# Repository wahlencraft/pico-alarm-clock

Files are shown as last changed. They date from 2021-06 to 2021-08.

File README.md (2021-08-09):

# Pico Alarm Clock

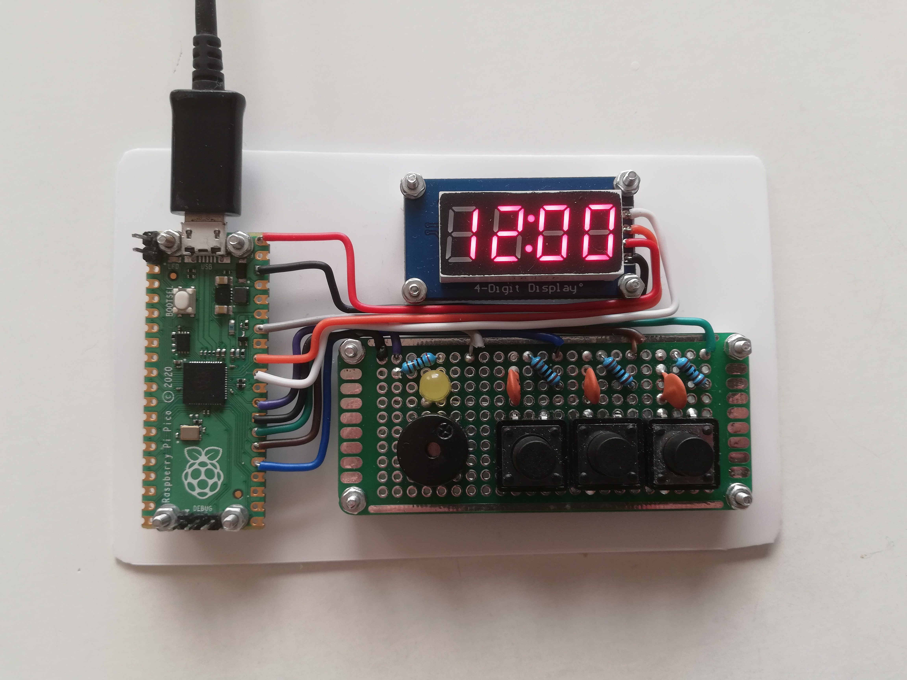
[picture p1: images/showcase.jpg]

## Introduction
This is an alarm clock that is running on Raspberry Pi Pico and is displaying
on a TM1637 7-segment display. In this project I try to stay close to the
hardware and implement what I can from scratch. For example, I wrote my own
library for the display and I use real hardware interrupts for button clicks and
time based events.

I made a short [YouTube video](https://youtu.be/I4LGKX7zu-I) showing some of the 
functionallity of the clock.

## Dependencies
* [Raspberry Pi Pico SDK](https://github.com/raspberrypi/pico-sdk): The
  standard library for working with Pico.
* [Pico Extras](https://github.com/raspberrypi/pico-extras): Some additional
  libraries. I needed this for putting the Pico in sleep mode.
* [TM1637-pico](https://github.com/wahlencraft/TM1637-pico): My own library for
  writing to the 7-segment display.

## Setup
### Hardware

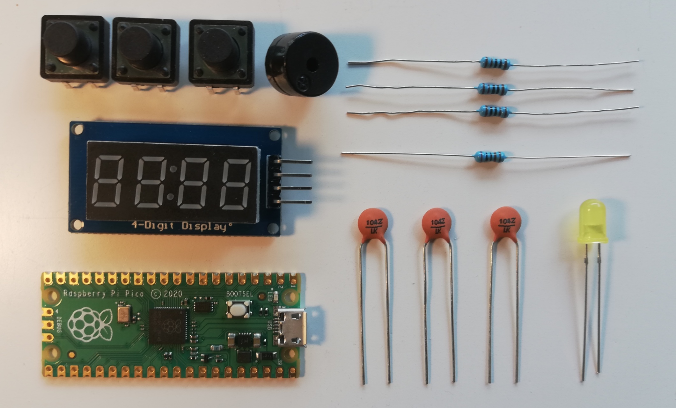
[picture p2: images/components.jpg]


* Raspberry Pi Pico
* TM1637 7-segment display
* Passive buzzer
* 3 Buttons
* Led (I used a yellow one)
* 4 Resistors: 3 for button debouncing (1k) and 1 for the LED (2k). Exact
  sizes are not important and might vary depending on the buttons and LED.
* 3 Ceramic capacitors (100 nF) for button debouncing.
* A micro USB power cable and 5V power supply.

### Circuit
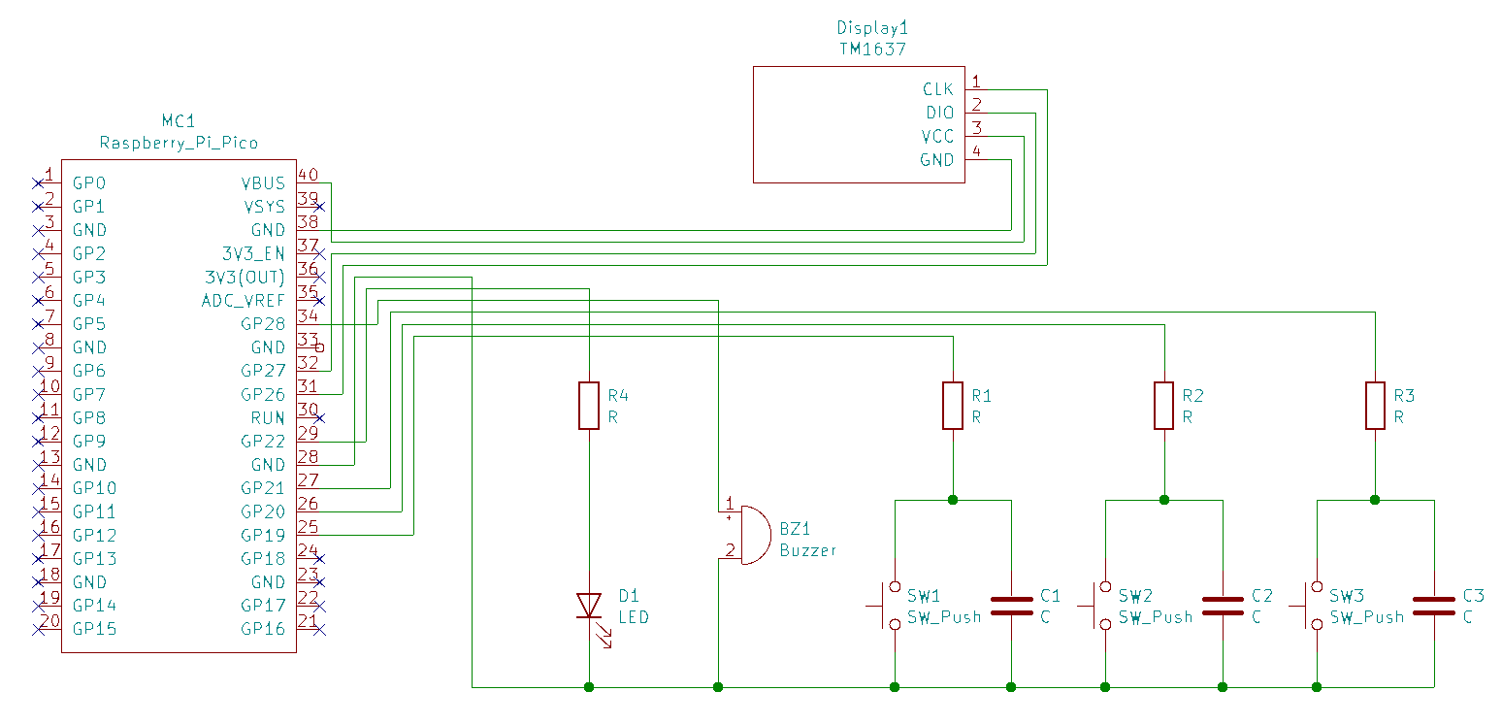
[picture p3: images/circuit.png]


### Load Code
A .elf and .uf2 binary can be downloaded for 1.0 or later. You can also clone the repository and build from source. Then the files will apear in the `build/src` directory.

#### UF2
Hold down the bootsel button and plug Rasperry Pi Pico into a USB port on your computer (Windows or Linux). The Pico will mount as a USB Mass Storage
Device. Drag and droop the .uf2 file on the Pico.

#### ELF
The .elf file can be loaded to the pico over UART. This is most easily done from a Rasperry Pi (computer), but can also be done with another Pico using Picoprobe. See [Getting started with Raspberry Pi Pico: Appendix A](https://datasheets.raspberrypi.org/pico/getting-started-with-pico.pdf)

If loading code over UART (from for example a Raspberry Pi) some unexpected
behavior arises.

The openocd reset command does not work with this code. I don't know why but a
workaround is to remove that from the command. Load code with:
`openocd -f interface/raspberrypi-swd.cfg -f target/rp2040.cfg -c "program src/alarm-clock.elf verify exit"`
Then restart the Pico manually by using a reset switch or un- and re-plugging the
power.

## Usage
Under normal circumstances will the display show current time and wait for
alarms to fire. When the clock is turned on the time will be `Monday 00:00:00`
and there is no set alarms. To change the time or add an alarm, open the menu.
### The Settings Menu
If any button is pressed the menu will open. In the menu you can change the
display brightness, set clock time and set alarms. See the flowchart below for
a quick overview or read the following sections for an in-depth description.
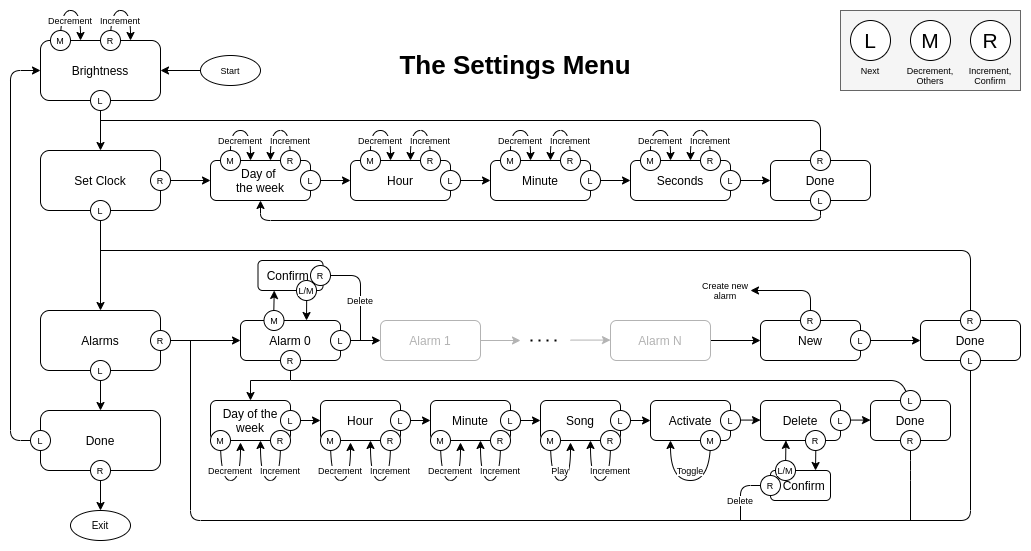
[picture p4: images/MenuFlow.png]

#### Brightness
In the brightness state the display will show `br: x`, where `x` will change with
the brightness level. In- or decrease the brightness with the M and R buttons.
The brightness has 8 levels, ranging from 0 to 7. Although there seems to be
a very little change in brightness in the higher levels.
#### Set Clock
To enter Set Clock press the R button when the display shows `SEt`. Here you
can change the running clock.
- **Day of the week** (`da:xx`): In or decrease with the M and R buttons.
  A list of the days and their two letters:
  - Monday: `mo`
  - Tuesday: `tU`
  - Wednesday: `wE`
  - Thursday: `tH`
  - Friday: `Fr`
  - Saturday: `SA`
  - Sunday: `SU`
- **Hour** (`Hr:xx`): In- or decrease with the M and R buttons.
- **Minute** (`mi:xx`): In- or decrease with the M and R buttons.
- **Seconds** (`SE:xx`): Zero the counter with the M or R button. Please note
  that this only sets the current second to 0, it doesn't restart the RTC. This
  makes it impossible to set exactly when a second starts.
- **Done** (`done`): Go back to the main menu.
#### Alarms
To enter Alarms press the R button when the display shows `ALAr`. Then you will
be navigated to the first alarm, called `AL: 0`. Given that this alarm exists.
Otherwise you will see `nEw` on the display.

To create a new alarm, navigate to `nEw` and press R. That will open the edit
state for a new alarm.

To edit an existing alarm, navigate to `AL: x` and press R.

Editing an alarm works a lot like setting the clock. With some differences:
- You can not specify seconds
- Song (`So`). This is what sound the alarm will make. Use the
  R button to increment song and M button to listen to it.
- Activate (`Act`): Toggle active status of this alarm. The LED will be on if
  the alarm is on and off if the alarm is off. When creating a new alarm is it
  by default on.
- Delete (`dEL`): Exit and delete the current alarm. Confirm deletion with R,
  abort with L or M.
- Done (`done`): Will fail if there already is an alarm with the same time.

Note that when exiting from `done`, you will always get to the first alarm
`AL: 0`. This is because the list of alarms will always be in chronological
order, and might need rearrangement after an edit.

To delete an alarm, navigate to it and press M. Then press R. To abort press
any other button.
### The Alarms
You can have an unlimited numbers of alarms. Every alarm has a time (specified
by day of the week, hour and minute), a song (what tones will play when it
fires) and an active status. To change these see [this section](#alarms).

When an alarm fires it will play it's song and blink the LED. It will continue
until any button is pressed to stop it or the max duration has passed (default
5 minutes).

## Making modifications
If you want to make some modifications to the program i would recommend
starting with these files.

* [pins.h](src/pins.h): Here you can change what physical pin will have what
  function. So if your prototype does not have the same connections as mine you
  need to make changes here.
* [timout_timer.h](src/timeout_timer.h): Here you will find `ALARM_TIMEOUT`
  which determines for how long an alarm should fire before turning off
  automatically.
* [song_def.c](src/song_def.c): Here the songs (alarm sounds) are
  defined. You can edit, add and remove songs. Please note that what tones that
  resonates best depends on your buzzer, so this might be necessary if you have
  a very different one from mine.

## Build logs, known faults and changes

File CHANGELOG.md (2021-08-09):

# Changelog

## [1.0.0] - 2021-08-09
### Added
- You can now delete an alarm directly from the alarm edit menu.
- You can now listen to a song directly from the alarm edit menu.
- New songs.
### Changed
- There is now a max duration for alarms (5 minutes).
- If attempting to add an alarm which collides with an already existing alarm,
  it will fail, and the display will blink.

## [0.3.0] - 2021-07-10
### Added
- Enable/Disable alarms
- LED support.
  - LED blinks along with the sound when an alarm is firing.
  - In alarm settings, LED indicate if alarm is disabled or enabled.

## [0.2.0] - 2021-06-24
### Added
- Create, edit and remove alarms
### Changed
- The brightness setting can now be increased and decreased, just like the other
  settings.

## [0.1.0] - 2021-06-15
### Added
- Show time in 24h format.
- A menu oriented with 3 buttons. Ability to change display brightness and
  clock time.
- Some work in progress for alarms:
  - Ability to play sounds (code only).
  - Ability to store alarms (code only).

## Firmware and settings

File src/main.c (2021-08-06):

/**
 * main.c
 *
 * Some important functions and the upper level state-machine.
 **/

/*******************************************************************************
 *  Includes
 ******************************************************************************/
#include <stdlib.h>
#include <stdio.h>
#include <stdbool.h>

#include <pico/stdlib.h>
#include <pico/sleep.h>
#include <hardware/rtc.h>
#include <pico/util/datetime.h>
#include <PicoTM1637.h>
#include <hardware/sync.h>

#include <pins.h>
#include <helpers.h>
#include <settings.h>
#include <node.h>
#include <alarm.h>
#include <timeout_timer.h>

/*******************************************************************************
 * Globals
 ******************************************************************************/

volatile struct GlobBinder *state;  // Binder for all states in the global state machine

/*******************************************************************************
 * Functions
 ******************************************************************************/

static void fire_alarm(void) {
  printf("START NEW ALARM\n");
  uint32_t hz = clock_get_hz(clk_sys);
  printf("  Running at %f MHz\n", (float) hz/1000000);
  state->alarmMode = true;
  start_alarm_timer();
}

static void gpio_callback(uint gpio, uint32_t events) {
  DEBUG_PRINT(("Interrupted by GPIO %d\n", gpio));
  DEBUG_PRINT(("  alarmMode: %d, sleepMode: %d, buttonBuffer: %d\n",
      state->alarmMode, state->sleepMode, state->buttonBuffer));
  if (state->alarmMode) {
    DEBUG_PRINT(("    Turn of alarm!\n"));
    state->alarmMode = false;
  } else {
    state->sleepMode = false;
    state->buttonBuffer = gpio;
  }
  DEBUG_PRINT(("  alarmMode: %d, sleepMode: %d, buttonBuffer: %d\n",
      state->alarmMode, state->sleepMode, state->buttonBuffer));
}

static int64_t alarm_callback(alarm_id_t id, void *user_data) {
  DEBUG_PRINT(("alarm_callback: Timer %d fired! ", (int) id));
  display_h_min();
  int64_t nextCallback = update_running_song();
  DEBUG_PRINT(("Again in %lld ms\n", nextCallback));
  // Can return a value here in us to fire in the future
  return nextCallback*1000;
}

static void setup_button(int gpio) {
  gpio_pull_up(gpio);
  gpio_set_irq_enabled_with_callback(
      gpio,
      GPIO_IRQ_EDGE_RISE,
      true,
      &gpio_callback
      );
}

/* Put cpu to sleep until next minute. Then display time. */
static void sleep_to_next_min() {
  // Set next wakeup
  datetime_t time = {
    .year = -1,
    .month = -1,
    .day = -1,
    .dotw = -1,
    .hour = -1,
    .min = -1,
    .sec = 0
  };
  uart_default_tx_wait_blocking();
  TM1637_wait();
  sleep_goto_sleep_until(&time, &display_h_min);
}

/* Put cpu to sleep until next alarm. Then display time and start alarmMode. */
void sleep_to_next_alarm(node_t *alarm) { 
  // Copy time
  datetime_t time;
  time.year = -1;
  time.month = -1;
  time.day = -1;
  time.dotw = alarm->time->dotw;
  time.hour = alarm->time->hour;
  time.min = alarm->time->min;
  time.sec = alarm->time->sec;
  
  // Prepare for sleep mode
  uart_default_tx_wait_blocking();
  TM1637_wait();
  
  // Go to sleep
  sleep_goto_sleep_until(&time, &fire_alarm);
}

/*******************************************************************************
 *  Main program
 *  - Initiate
 *  - Start main loop (the state machine)
 ******************************************************************************/
int main() {

  struct GlobBinder globalStruct = {.sleepMode = true, .buttonBuffer = 0};
  state = &globalStruct;
  
  stdio_init_all();
  uart_default_tx_wait_blocking();

  // Initiate
  TM1637_init(CLK_PIN, DIO_PIN);
  setup_button(LEFT_BUTTON);
  setup_button(MIDDLE_BUTTON);
  setup_button(RIGHT_BUTTON);
  DEBUG_WAIT((100));
  init_alarms();

  TM1637_clear();
  // Start the RTC
  rtc_init();
  datetime_t t = {
    .year = 1970,
    .month = 1,
    .day = 1,
    .dotw = 1, // 0 is Sunday
    .hour = 0,
    .min = 0,
    .sec = 0
  };

  // Switch to XOSC
  uart_default_tx_wait_blocking();
  sleep_run_from_xosc();
  TM1637_refresh_frequency();

  rtc_set_datetime(&t);

  // Setting cases
  #define SETT_NONE 0
  #define SETT_BRIGHT 1
  #define SETT_CLOCK 2
  #define SETT_ALARM 3
  #define SETT_DONE 4

  display_h_min();
  state->sleepMode = true;
  state->alarmMode = false;
  state->buttonBuffer = 0;

  node_t *runningAlarm = malloc(sizeof(runningAlarm));
  runningAlarm->time = malloc(sizeof(datetime_t));

  DEBUG_PRINT(("\nSTART MAIN LOOP\n"));
  // Main loop
  //
  // if alarmMode:
  //    play song (stay here until interupt)
  // else if sleepMode:
  //    if "alarm in 1 min" -> sleep_to_next_alarm
  //    else -> sleep_to_next_min
  // else: (button interupt)
  //    open settings menu
  while (true) {
    DEBUG_PRINT(("\n"));
    print_current_time();
    print_all_alarms();
    if (state->alarmMode) {
      rtc_disable_alarm();
      start_song(runningAlarm->song);
      alarm_id_t almID = add_alarm_in_us(0, alarm_callback, NULL, true);
      DEBUG_PRINT(("Alarm %d started\n", almID));
      while (state->alarmMode) {
        if (alarm_timeout()) {
          state->alarmMode = false;
          DEBUG_PRINT(("Alarm fired for too long. Turning off.\n"));
          break;
        }
      }
      cancel_alarm(almID);
      stop_song();
    } else if (state->sleepMode) {
      if (is_alarm_in_1_min(runningAlarm)) {
        DEBUG_PRINT(("Found Alarm! Fire at "));
        print_time(runningAlarm->time, 0);
        sleep_to_next_alarm(runningAlarm);
      } else {
        sleep_to_next_min();
      }
    } else {
      // Interrupted from by button. Open settings menu.
      rtc_disable_alarm();
      DEBUG_PRINT(("Woke up by interupt!\n"));
      int button;
      int setting = 1;
      state->buttonBuffer = 0;
      while (setting != 0) {
        DEBUG_PRINT(("Outer setting loop. Case is %d\n", setting));
        switch (setting) {

          case SETT_BRIGHT:
            DEBUG_PRINT((" Enter SETT_BRIGHT\n"));
            setting = brightness_setting(SETT_BRIGHT);
            break;

          case SETT_CLOCK:
            DEBUG_PRINT((" Enter SETT_CLOCK\n"));
            setting = set_clock_setting(SETT_CLOCK);
            break;

          case SETT_ALARM:
            DEBUG_PRINT((" Enter SETT_ALARM\n"));
            setting = set_alarm_setting(SETT_ALARM);
            break;

          case SETT_DONE:
            DEBUG_PRINT((" Enter SETT_DONE\n"));
            setting = done_setting(SETT_DONE);
            break;

          default:
            // Should not happen
            DEBUG_PRINT(("Runntime Error, buttonBuffer = %d\n",
                  state->buttonBuffer));
            return 1;
        }
      }
      // Exit settings menu.
      display_h_min();
      state->sleepMode = true;
    }
  }
}

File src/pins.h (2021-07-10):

#ifndef PINS_H_H
#define PINS_H_H

/**
 * pins.h
 *
 * Define all the pin conections for the prototype.
 **/

// TM1637 7-segment display
#define CLK_PIN 26
#define DIO_PIN 27

 // Piezo buzzer
#define BUZ_PIN 28

// Buttons
#define RIGHT_BUTTON 21
#define MIDDLE_BUTTON 20
#define LEFT_BUTTON 19

// LED
#define LED_PIN 22

#endif // PINS_H_h

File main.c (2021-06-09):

/**
 * main.c
 *
 * Some important functions and the upper level state-machine.
 **/

/*******************************************************************************
 *  Includes
 ******************************************************************************/
#include <stdlib.h>
#include <stdio.h>
#include <stdbool.h>

#include <pico/stdlib.h>
#include <pico/sleep.h>
#include <hardware/rtc.h>
#include <pico/util/datetime.h>
#include <PicoTM1637.h>
#include <hardware/sync.h>

#include <helpers.h>
#include <settings.h>
#include <node.h>
#include <alarm.h>

/*******************************************************************************
 * Globals
 ******************************************************************************/
// Global constants
#define CLK_PIN 27
#define DIO_PIN 26
#define BUZ_PIN 15
#define RIGHT_BUTTON 22
#define MIDDLE_BUTTON 21
#define LEFT_BUTTON 20
#define BUZZER_DELAY 500

// Global declarations
volatile struct GlobBinder *state;  // Binder for all states in the global state machine 
/*******************************************************************************
 * Functions 
 ******************************************************************************/

void rtc_alarm_callback(void) {
  printf("RTC ALARM -> alarm()\n");
  state->sleepMode = false;
  state->alarmMode = true;
}

void gpio_callback(uint gpio, uint32_t events) {
  printf("    { Interrupted by %d\n", gpio);
  state->sleepMode = false;
  state->buttonBuffer = gpio;
  printf("      buttonBuffer = %d }\n", state->buttonBuffer);
}

int64_t alarm_callback(alarm_id_t id, void *user_data) {
    static int counter = 100;
    printf("Timer %d fired! ", (int) id);
    int64_t nextCallback = update_running_alarm();
    printf("Again in %lld ms\n", nextCallback);
    // Can return a value here in us to fire in the future
    if (counter--) {
      return nextCallback*1000;
    } else {
      state->alarmMode = false;
      return 0;
    }
}

void setup_button(int gpio) {
  gpio_pull_up(gpio); 
  gpio_set_irq_enabled_with_callback(
      gpio, 
      GPIO_IRQ_EDGE_RISE, 
      true, 
      &gpio_callback
      );
}

void show_next_min() {
  char strBuff[63];
  // Print current time
  datetime_t t;
  rtc_get_datetime(&t);
  datetime_to_str(strBuff, 63, &t);
  printf("Current time: %s\n", strBuff);
  // Set next wakeup
  datetime_t time = {
    .year = -1,
    .month = -1,
    .day = -1,
    .dotw = -1,
    .hour = -1,
    .min = -1,
    .sec = 0
  };
  uart_default_tx_wait_blocking(); 
  TM1637_wait();
  sleep_goto_sleep_until(&time, &display_h_min);
}

/*******************************************************************************
 *  Main program
 *  - Initiate
 *  - Start main loop (the state machine)
 ******************************************************************************/
int main() {

  struct GlobBinder globalStruct = {.sleepMode = true, .buttonBuffer = 0};
  state = &globalStruct;

  // Initiate
  stdio_init_all();
  TM1637_init(CLK_PIN, DIO_PIN);
  gpio_init(BUZ_PIN);
  gpio_set_dir(BUZ_PIN, GPIO_OUT);
  setup_button(LEFT_BUTTON);
  setup_button(MIDDLE_BUTTON);
  setup_button(RIGHT_BUTTON);

  TM1637_clear();
  printf("\n--NEW TEST--\n");
  
  // Start the RTC
  rtc_init();
  datetime_t t = {
    .year = 1970,
    .month = 1,
    .day = 1,
    .dotw = 1, // 0 is Sunday
    .hour = 0,
    .min = 0,
    .sec = 0
  };
  
  // Switch to XOSC
  uart_default_tx_wait_blocking();
  sleep_run_from_xosc();
  TM1637_refresh_frequency();
  
  rtc_set_datetime(&t);
  
  // Setting cases
  #define SETT_NONE 0
  #define SETT_BRIGHT 1
  #define SETT_CLOCK 2
  #define SETT_ALARM 3
  #define SETT_DONE 4
  
  init_alarms();

  printf("Start alarm...\n");
  printf("Wait for alarm...\n");

  printf("Start main loop\n");
  display_h_min();
  state->sleepMode = true;
  state->alarmMode = false;
  state->buttonBuffer = 0;

  // for testing purposes
  state->sleepMode = false;
  state->alarmMode = true;

  // Main loop
  while (true) {
    if (state->sleepMode) {
      show_next_min();
    } else if (state->alarmMode) {
      rtc_disable_alarm();
      printf("Alarm!!!\n");
      start_alarm(1);
      add_alarm_in_ms(1, alarm_callback, NULL, false);
      while (state->alarmMode) {}
      stop_alarm();
      state->sleepMode = true;
    } else {
      // Interrupted from sleepmode
      rtc_disable_alarm();
      printf("Woke up by interupt!\n");
      int button;
      state->setting = 1;
      state->buttonBuffer = 0;
      while (state->setting != 0) {
        printf("Outer setting loop. Case is %d\n", state->setting);
        switch (state->setting) {
          
          case SETT_BRIGHT:
            printf(" Enter SETT_BRIGHT\n");
            brightness_setting(SETT_BRIGHT);
            break;
          
          case SETT_CLOCK:
            printf(" Enter SETT_CLOCK\n");
            set_clock_setting(SETT_CLOCK);
            break;
        
          case SETT_ALARM:
            printf(" Enter SETT_ALARM\n");
            set_alarm_setting(SETT_ALARM);
            break;
          
          case SETT_DONE:
            printf(" Enter SETT_DONE\n");
            done_setting(SETT_DONE);
            break;
          
          default:
            // Should not happen
            printf("Runntime Error, buttonBuffer = %d\n", state->buttonBuffer);
            return -1;
        }
      }
    }
  }
}

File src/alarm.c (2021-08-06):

#include <alarm.h>

/*******************************************************************************
 *  Typedefs
 ******************************************************************************/
typedef struct SongState {
  note_t **start;  // Pointer to pointer of start of song
  int index;  // what tone (index) should be played?
  int phase;  // 0: play phase, 1: wait phase
} song_state_t;

/*******************************************************************************
 * Globals
 ******************************************************************************/
node_t *alarms;
static note_t ***songs;
static volatile song_state_t songState;
int SONGS;

/*******************************************************************************
 * Initialization
 ******************************************************************************/

void init_alarms() {
  DEBUG_PRINT(("\nINIT ALARMS\n"));
  // LED
  gpio_init(LED_PIN);
  gpio_set_dir(LED_PIN, GPIO_OUT);
  
  // PWM
  gpio_init(BUZ_PIN);
  gpio_set_dir(BUZ_PIN, GPIO_OUT);
  gpio_set_function(BUZ_PIN, GPIO_FUNC_PWM);
  uint slice_num = pwm_gpio_to_slice_num(BUZ_PIN);
  uint channel = pwm_gpio_to_channel(BUZ_PIN);
  pwm_set_wrap(slice_num, 31);
  pwm_set_chan_level(slice_num, channel, 15);
  
  int index = 0;
  
  // Allocate
  SONGS = get_num_of_songs();
  DEBUG_PRINT(("Found %d songs", SONGS));
  songs = malloc(sizeof(note_t**)*SONGS);

  for (int song=0; song<SONGS; song++) {
    songs[song] = &allNotes[index];
    while (allNotes[++index] != NULL) {}
    index++;
  }
# ifdef DEBUG
  printf(" (0x%x)\n", songs);
  for (int song=0; song<SONGS; song++) {
    printf("  songs[%d]: 0x%x", song, songs[song]);
  }
  printf("\n");

  printf("Print notes\n");
  for (int song=0; song<SONGS; song++) {
    note_t *note = *songs[song];
    int i = 1;
    do {
      printf(" |0x%x %d %d/%d|", note, note->freq, note->playDuration, note->waitDuration);
      note = *(songs[song] + i++);
    } while (note != NULL);
    printf("\n");
  }
# endif
}


/*******************************************************************************
 * LED functions
 ******************************************************************************/
static void drive_led_high(bool high) {
  gpio_put(LED_PIN, high);
}

void show_if_alarm_active(node_t *alarm) {
  gpio_put(LED_PIN, alarm->active);
}

void led_clear() {
  gpio_put(LED_PIN, false);
}

/*******************************************************************************
 * Song functions
 ******************************************************************************/
int get_number_of_songs() {
  return SONGS;
}

void start_song(int songNum) {
  DEBUG_PRINT(("Start song %d\n", songNum));
  songState.start = songs[songNum];
  songState.index = 0;
  songState.phase = 0;
}

void stop_song() {
  DEBUG_PRINT(("Stop song\n"));
  uint slice_num = pwm_gpio_to_slice_num(BUZ_PIN);
  pwm_set_enabled(slice_num, false);
  drive_led_high(false);
}

int64_t update_running_song(void) {
  // For every note this function is called twice.
  // What is done depends on the contents of the global struct songState
  //  songState.start: Pointer to pointer of first note in song.
  //  songState.index: What note that is playing.
  //  songState.phase: Phase for note (0 or 1).
  //    0. Play sound, return playDuration.
  //    1. Silent, return waitDuration.
  //note_t **notes = songList[songState.num]->notes;
  note_t *note = *(songState.start + songState.index);
  int64_t retval;
  uint32_t sysFreq = clock_get_hz(clk_sys);
  uint slice_num = pwm_gpio_to_slice_num(BUZ_PIN);
  if (songState.phase == 0) {
    pwm_set_clkdiv(slice_num, sysFreq/note->freq);
    pwm_set_enabled(slice_num, true);
    songState.phase = 1;
    retval = note->playDuration;
    drive_led_high(true);
  } else {
    // phase 1
    pwm_set_enabled(slice_num, false);
    songState.index = (*(songState.start+songState.index+1) == NULL) ? 
      0 : songState.index + 1;
    songState.phase = 0;
    retval = note->waitDuration;
    drive_led_high(false);
  }
  return retval;
}
/*******************************************************************************
 * Alarm functions
 ******************************************************************************/
int add_alarm(datetime_t *time, int song, bool active) {
  node_t *newAlarm = malloc(sizeof(node_t));
  newAlarm->time = malloc(sizeof(datetime_t));
  deep_copy_time(time, newAlarm->time);
  newAlarm->song = song;
  newAlarm->active = active;
  DEBUG_PRINT(("Adding alarm:"));
  node_print(newAlarm, 2);
  if (node_add(&alarms, newAlarm)) {
    // Failed to add. Datetime occupied.
    DEBUG_PRINT(("Failed to add new alarm. There is already an alarm at this time.\n"));
    return EXIT_FAILURE;
  }
  return EXIT_SUCCESS;
}

int get_next_alarm(node_t *alarm, bool restart) {
  static node_t *node = NULL;
  if (!is_alarms()) {
    return EXIT_FAILURE;
  }
  if (restart) {
    node = alarms;
  } else if (node == NULL) {
    printf("ERROR in function %s on line &d, never restarted\n", 
        __func__, __LINE__);
    return EXIT_FAILURE;
  } else if (node->next != NULL) {
    node = node->next;
  } else {
    return EXIT_FAILURE;
  }
  alarm->song = node->song;
  alarm->active = node->active;
  deep_copy_time(node->time, alarm->time);
  return EXIT_SUCCESS;
}

bool is_alarms() {
  if (node_is_empty(alarms)) {
    return false;
  } else {
    return true;
  }
}

bool is_alarm_in_1_min(node_t *nextNode) {
  datetime_t t_now;
  rtc_get_datetime(&t_now);
  if (!is_alarms()) {
    return false;
  }
  if (node_get_next_from_time(&t_now, alarms, nextNode)) {
    // There is no next node
    DEBUG_PRINT(("There is no next alarm.\n"));
    return false;
  }
  if (!(nextNode->active)) {
    DEBUG_PRINT(("Next alarm disabled\n"));
    return false;
  }
  increment_datetime(&t_now, 1);
  datetime_t *t_nextMin = &t_now;
  t_nextMin->sec = 0;  // increment datetime did not touch seconds.
  switch (compare_datetimes(nextNode->time, t_nextMin)) {
    case DATETIME_BEFORE:
    case DATETIME_SAME:
      nextNode = nextNode;
      return true;
    case DATETIME_AFTER:
      DEBUG_PRINT(("Next alarm is in more than 1 minute.\n"));
      nextNode = NULL;
      return false;
  }
}

void print_all_alarms() {
# ifdef DEBUG
  printf("Printing all alarms.\n");
  node_print_all(alarms);
# endif
}

void remove_alarm(datetime_t *time, node_t *copy) {
  if (node_remove(&alarms, time, copy)) {
    // Failed to remove alarm. Alarm did not exist. TODO.
#   ifdef NDEBUG
      printf("  Tried to remove alarm, but alarm did not exist.\n");
      print_all_alarms();
#   endif
  }
}

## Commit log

2021-05-09 Button input
2021-05-18 Load button buffer with irq disabled
2021-06-12 Print statements that only appears on debug mode.
2021-06-15 Error message in case of failed head creation.
2021-06-16 Stop alarm with button press.
2021-06-17 Fix: Save new copy of datetime.
    [main.c]
2021-06-17 Fix: Old alarm callback fire late.
    [alarm.c, main.c]
2021-06-18 Flow chart for the menu
2021-06-21 Print current time for debugging
2021-06-24 Fix error in the flowchart
2021-06-24 Add a picture of the prototype
2021-06-28 Drive LED on alarm
2021-07-09 Light led for active alarms. Removing broken.
    [alarm.c, main.c]
2021-07-10 Use pins for the prototype
2021-07-15 Update menu flow for deletion in edit alarm mode.
2021-08-02 Fail to add alarms which already exits, blink display.
    [alarm.c]
2021-08-06 Clearup. Hide debug prints
